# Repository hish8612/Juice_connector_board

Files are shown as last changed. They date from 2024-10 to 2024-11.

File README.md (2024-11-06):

# [Radioberry_Juice_connector_board](https://github.com/hish8612/Juice_connector_board)

 beta0.1 Release

This project provides information on how to build an [radioberry-juice](https://github.com/pa3gsb/Radioberry-2.x/tree/master/hardware/juice) using the FT2232HL Development Learning Board, available at low cost on Aliexpress and eBay. (abt. $13 to $18)<br>
Connector boards make it easy to connect the Radioberry-2 to the FT2232HL Learning Board.<br>

#### Juice View and Connection

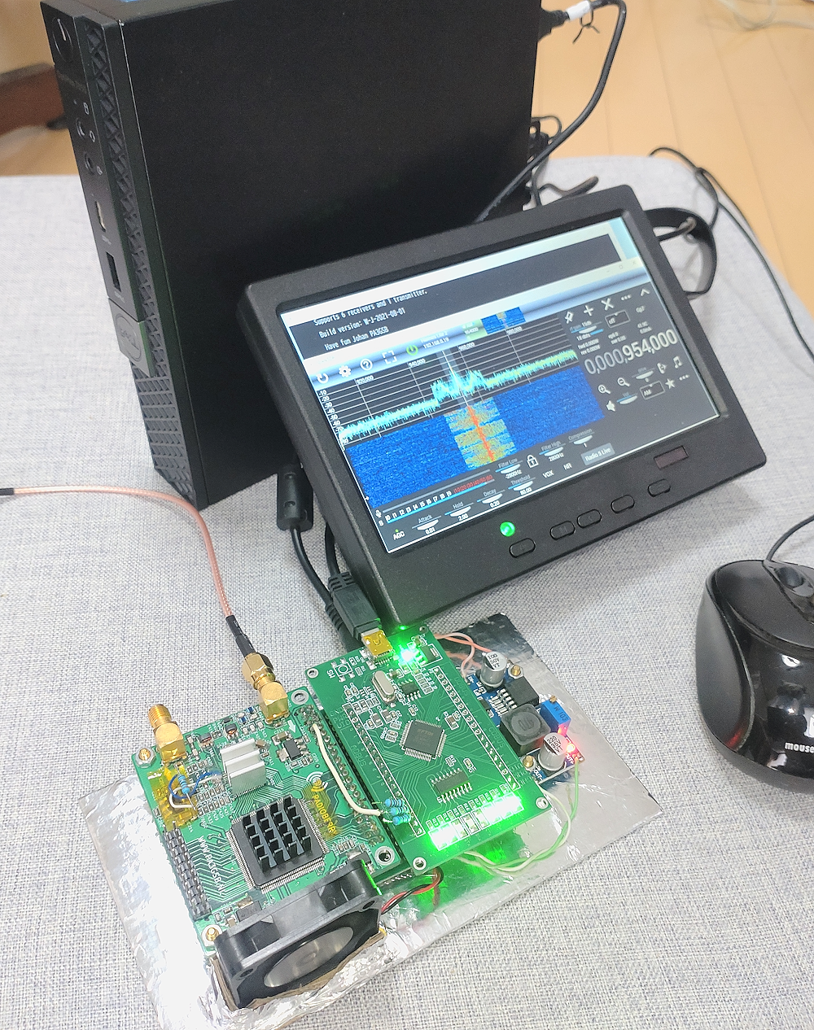
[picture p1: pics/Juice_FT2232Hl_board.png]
<br>
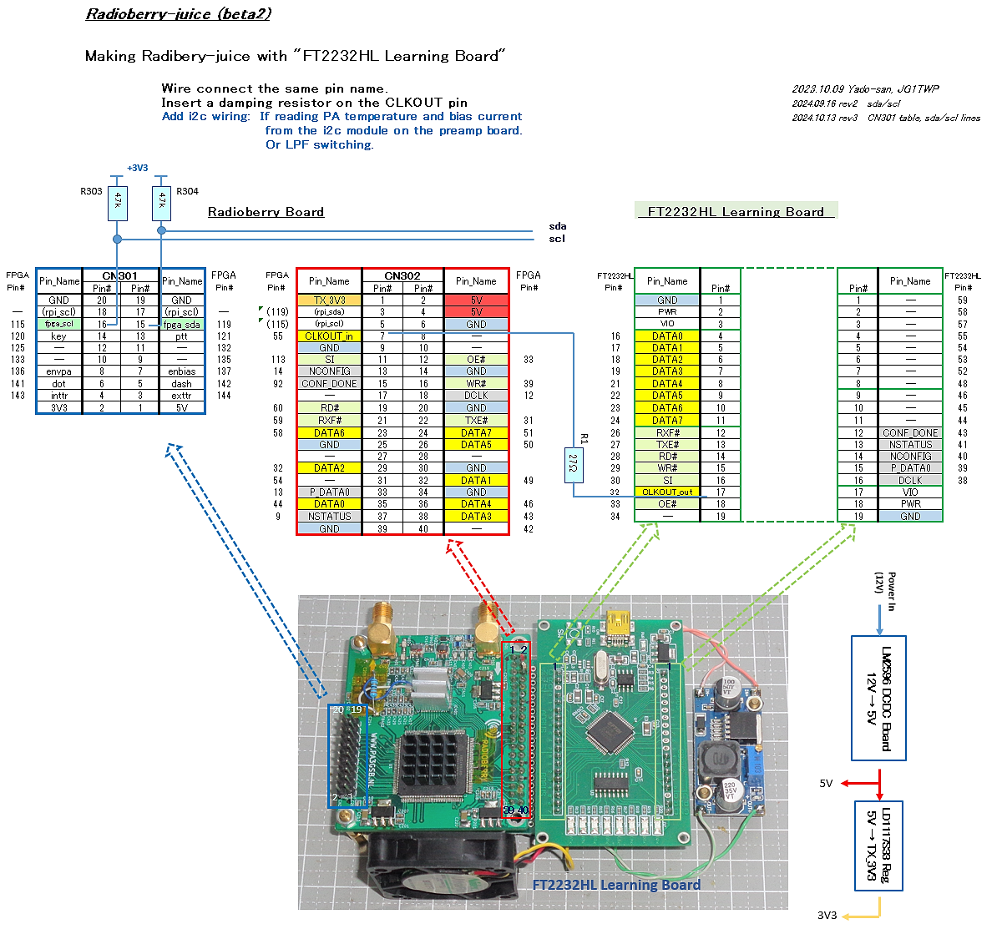
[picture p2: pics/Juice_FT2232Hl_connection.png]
<br>

#### Connetor board View
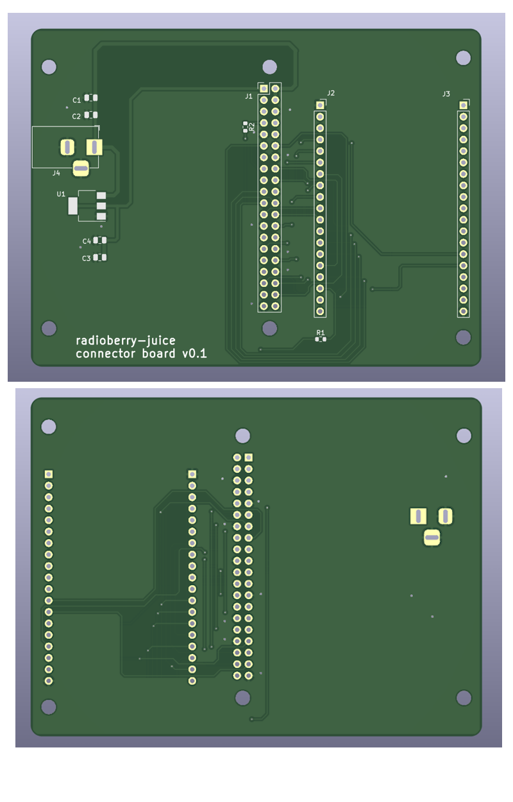
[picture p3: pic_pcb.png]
<br>
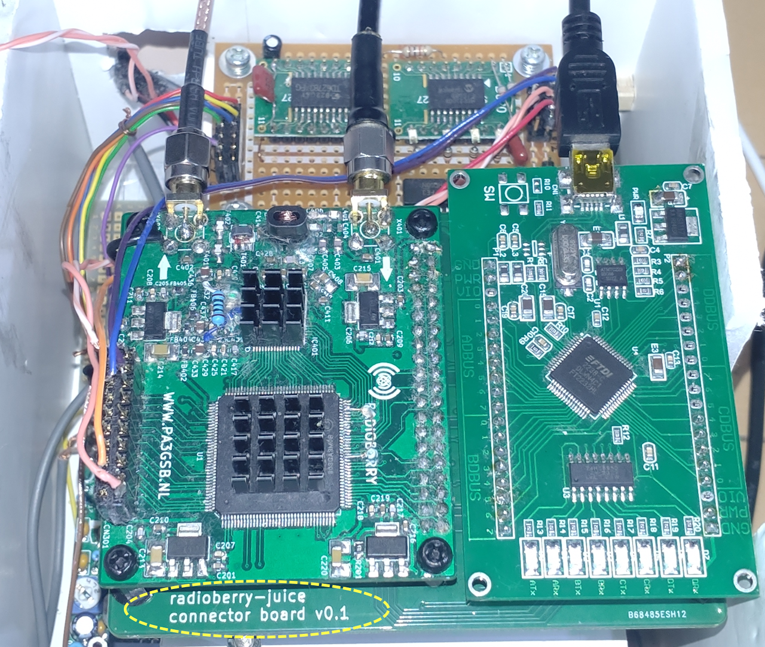
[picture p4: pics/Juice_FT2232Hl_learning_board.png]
<br>

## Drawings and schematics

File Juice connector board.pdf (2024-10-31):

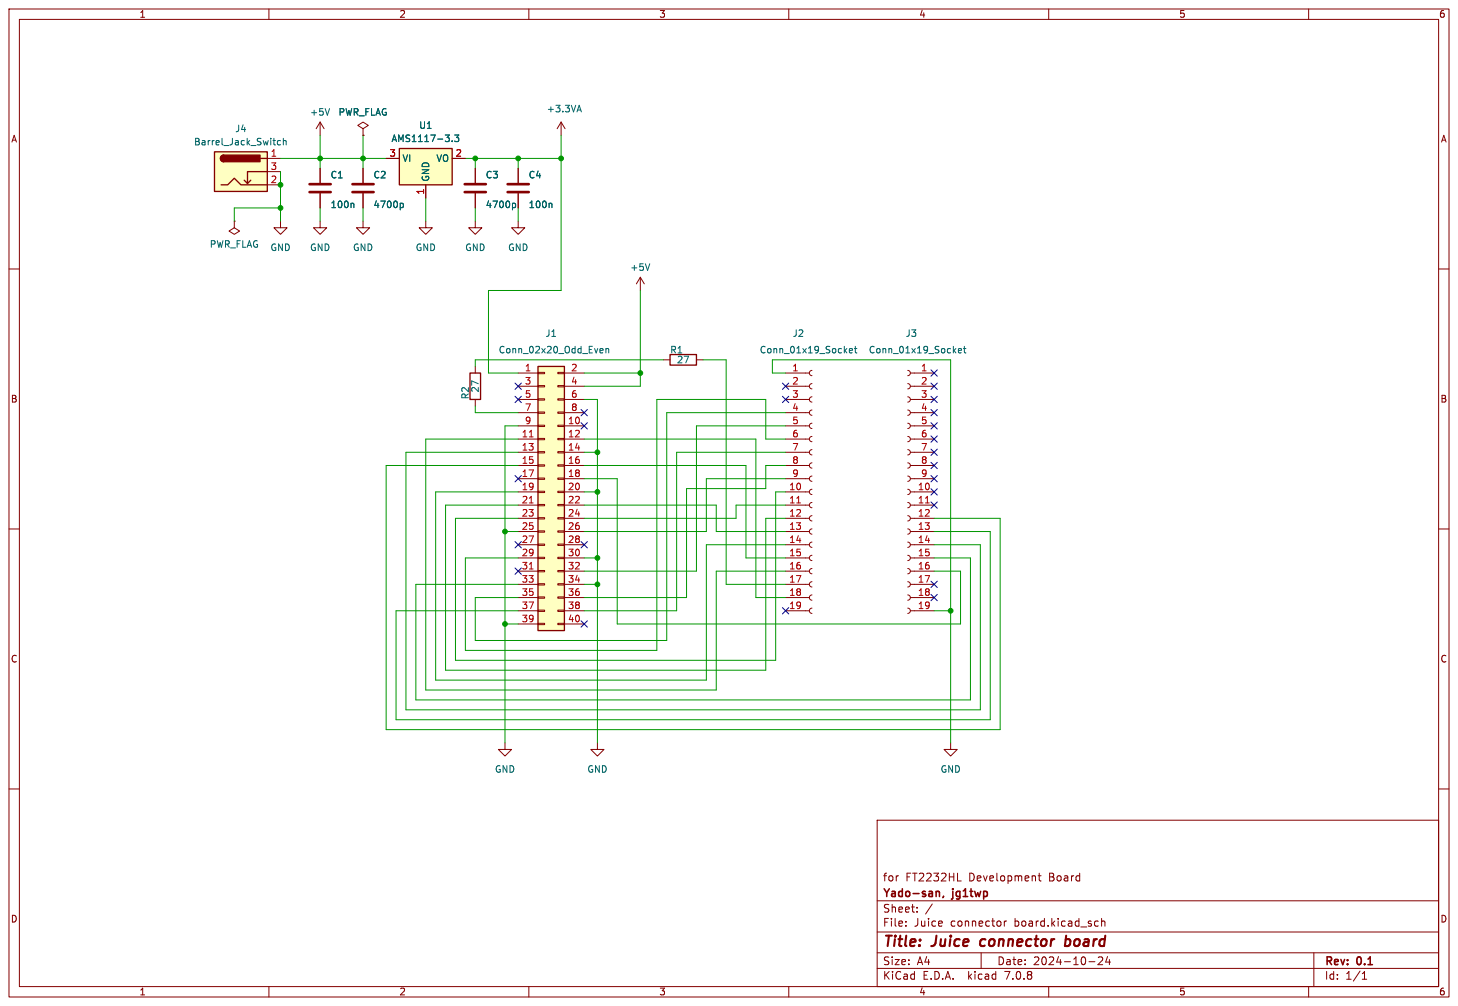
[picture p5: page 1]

Id: 1/1 Title: Juice connector board

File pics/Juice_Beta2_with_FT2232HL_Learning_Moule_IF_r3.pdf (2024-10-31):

## Radioberry-juice (beta2)

## Making Radibery-juice with "FT2232HL Learning Board"

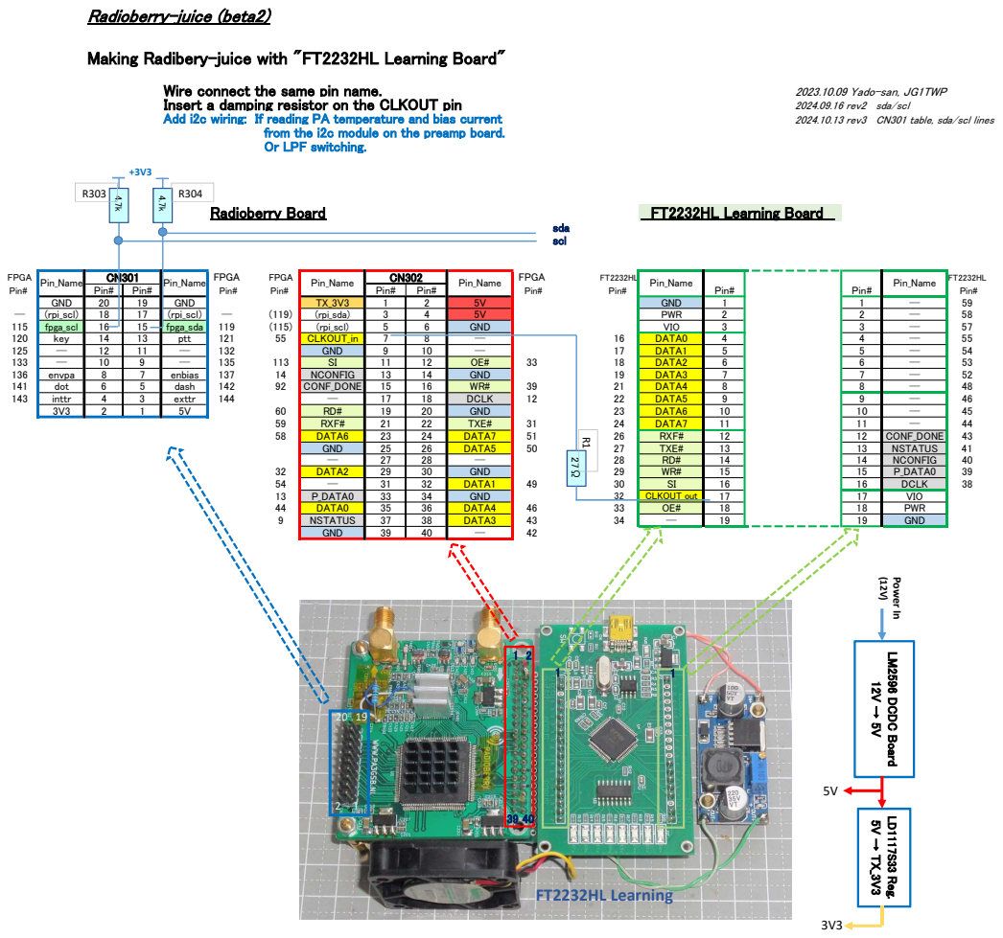
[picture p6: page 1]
Wire connect the same pin name.; 2023.10.09 Yado-san, JG1TWP; Insert a damping resistor on the CLKOUT pin; 2024.09.16 rev2 sda/scl; Add i2c wiring: If reading PA temperature and bias current; 2024.10.13 rev3 CN301 table, sda/scl lines; Radioberry Board; FT2232HL Learning Board; sda scl; FPGA; Pin#; GND; (rpi_scl); (rpi_sda); PWR; fpga_scl; fpga_sda; VIO; key; ptt; CLKOUT_in; DATA0; DATA1; DATA2; envpa; enbias; NCONFIG; DATA3; dot; dash; CONF_DONE; DATA4; inttr; exttr; DCLK; DATA5; DATA6; RXF#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

from the i2c module on the preamp board.
Or LPF switching.

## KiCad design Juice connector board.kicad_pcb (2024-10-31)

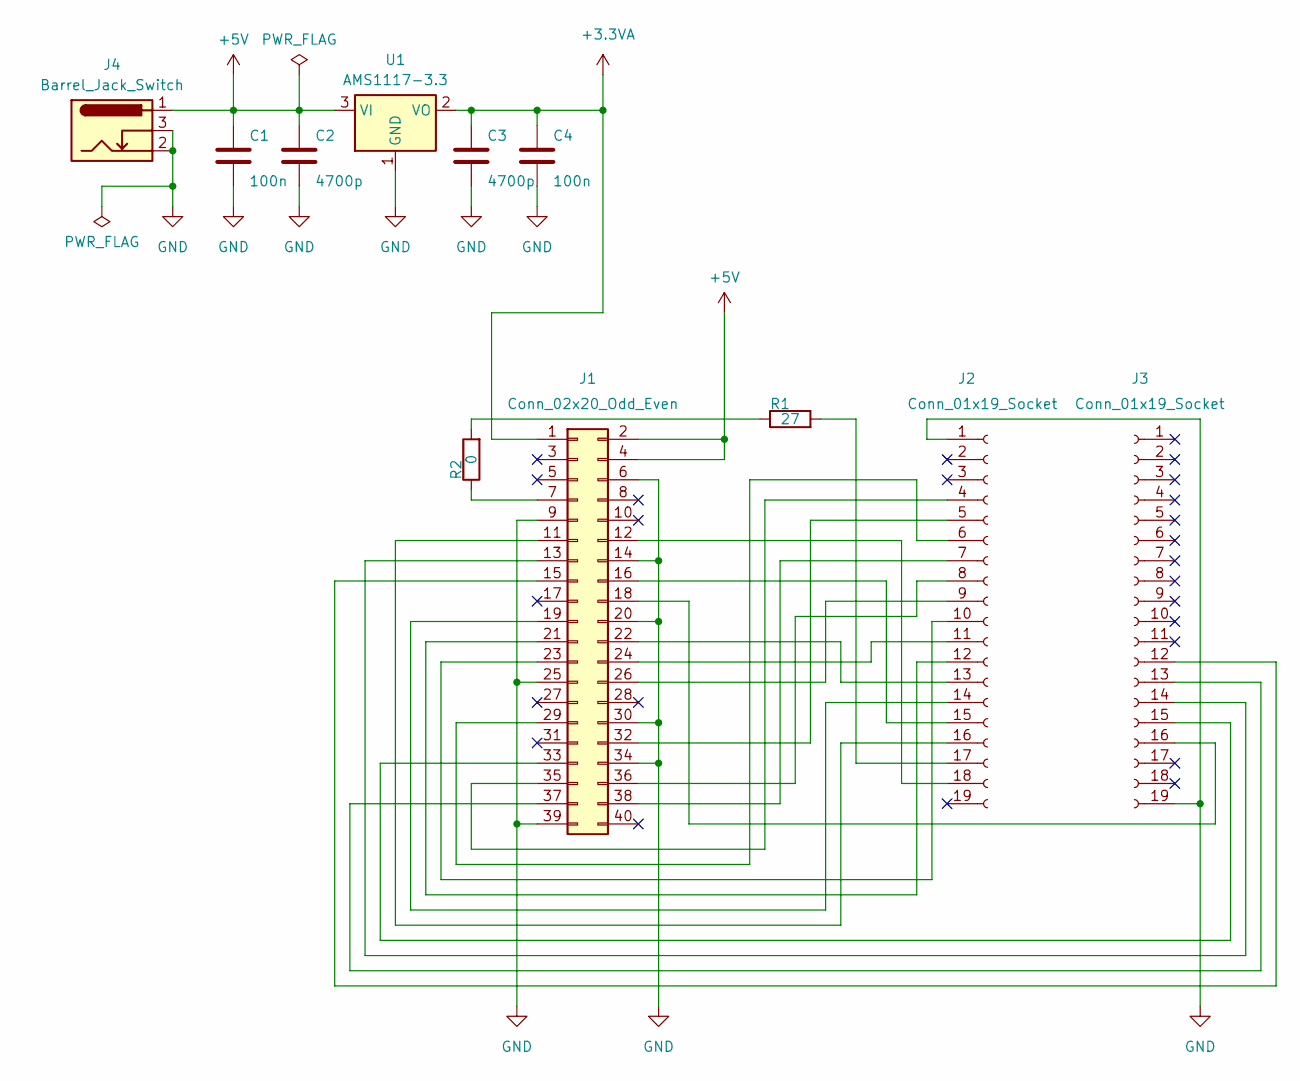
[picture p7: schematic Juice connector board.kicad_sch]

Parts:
C1, C4: 100n; C_0805_2012Metric
C2, C3: 4700p; C_0805_2012Metric
J1: Conn_02x20_Odd_Even; PinHeader_2x20_P2.54mm_Vertical
J2, J3: Conn_01x19_Socket; PinSocket_1x19_P2.54mm_Vertical
J4: Barrel_Jack_Switch; BarrelJack_Horizontal
R1: 27; R_0603_1608Metric
R2: 0; R_0603_1608Metric
U1: AMS1117-3.3; SOT-223-3_TabPin2

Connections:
+3.3VA: C3.1, C4.1, J1.1, U1.2 (VO)
+5V: C1.1, C2.1, J1.2, J1.4, J4.1, U1.3 (VI)
GND: C1.2, C2.2, C3.2, C4.2, J1.6, J1.9, J1.14, J1.20, J1.25, J1.30, J1.34, J1.39, J2.1, J3.19, J4.2, J4.3, U1.1 (GND)
unnamed: J1.7, R2.1
unnamed: J1.11, J2.16
unnamed: J1.12, J2.18
unnamed: J1.13, J3.14
unnamed: J1.15, J3.12
unnamed: J1.16, J2.15
unnamed: J1.18, J3.16
unnamed: J1.19, J2.14
unnamed: J1.21, J2.12
unnamed: J1.22, J2.13
unnamed: J1.23, J2.10
unnamed: J1.24, J2.11
unnamed: J1.26, J2.9
unnamed: J1.29, J2.6
unnamed: J1.32, J2.5
unnamed: J1.33, J3.15
unnamed: J1.35, J2.4
unnamed: J1.36, J2.8
unnamed: J1.37, J3.13
unnamed: J1.38, J2.7
unnamed: J2.17, R1.2
unnamed: R1.1, R2.2

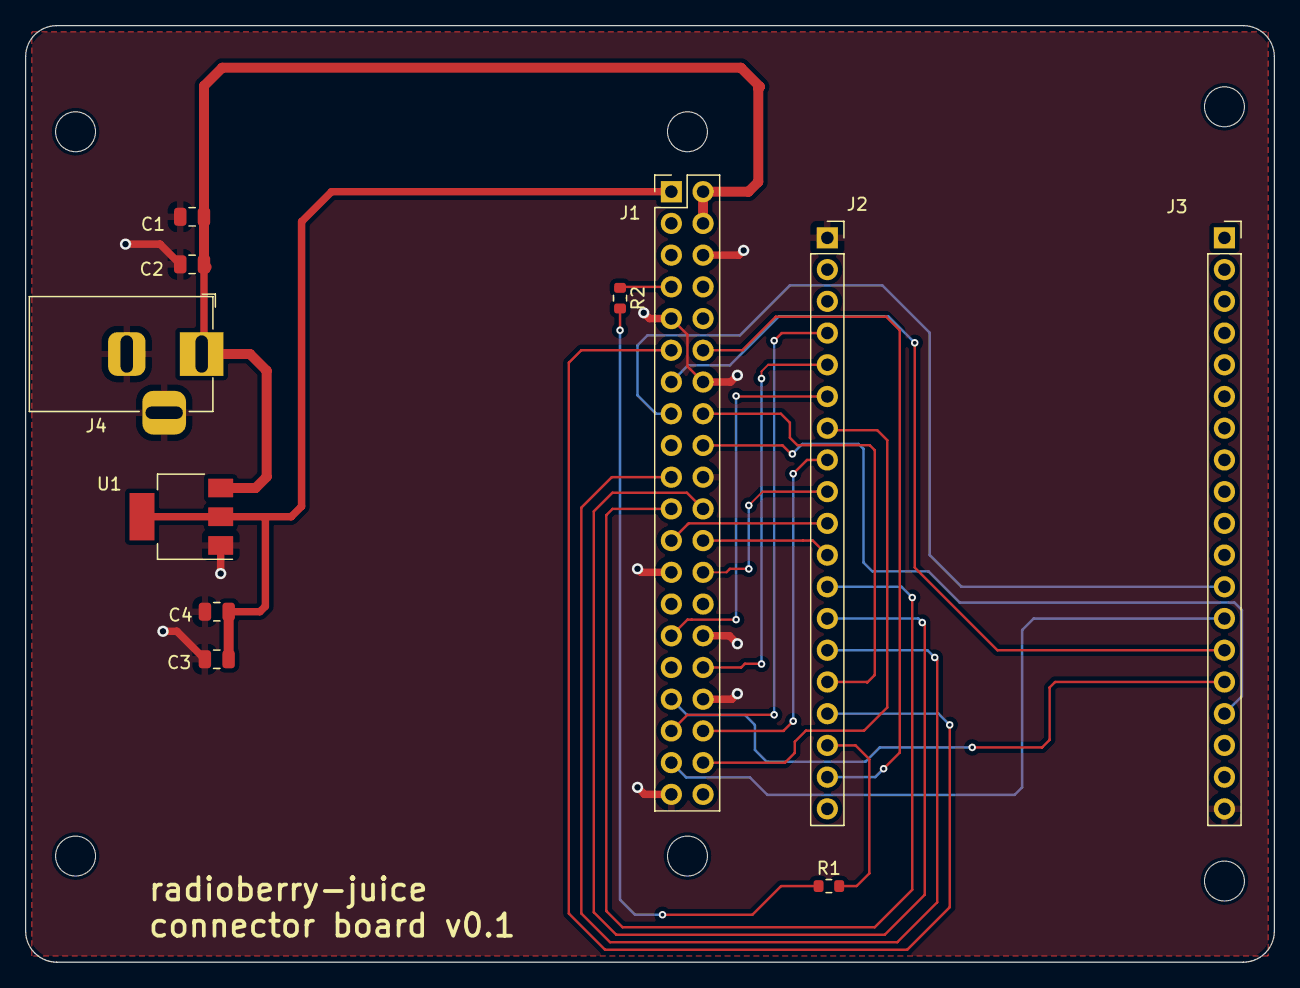
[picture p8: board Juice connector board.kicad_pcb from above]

Board: 2 copper layers, 100.0 x 75.0 mm, 17 parts (0 on the bottom side), 25 nets.

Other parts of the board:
MH1, MH2, MH3, MH4, MH5, MH6: MountingHole_3.2mm_M3
